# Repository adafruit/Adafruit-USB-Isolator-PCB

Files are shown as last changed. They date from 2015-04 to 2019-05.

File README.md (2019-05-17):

# Adafruit USB Isolator PCB
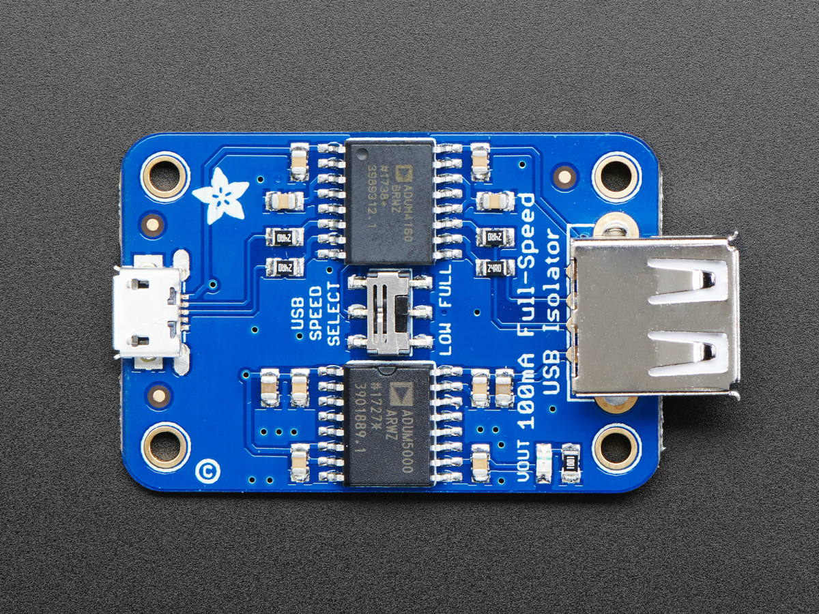
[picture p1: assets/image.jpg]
<a href="http://www.adafruit.com/products/2107"><br/>
Click here to purchase one from the Adafruit shop</a>

This handy little low-cost USB Isolator is exactly what you need to provide protection against harmful noise, ground loops, surges, and spikes. Works with any 1.5Mbps (low speed) or 12Mbps (full speed) USB device. Not for high speed USB devices, often used for video cameras (check your product to make sure its low/full compatible) Based on Analog Device's USB isolators

PCB files for the Adafruit USB Isolator. The format is EagleCAD schematic and board layout
- https://www.adafruit.com/product/2107

### License

Adafruit invests time and resources providing this open source design, please support Adafruit and open-source hardware by purchasing products from [Adafruit](https://www.adafruit.com)!

All text above must be included in any redistribution

Designed by Limor Fried/Ladyada for Adafruit Industries.
Creative Commons Attribution/Share-Alike, all text above must be included in any redistribution. 
See license.txt for additional information.

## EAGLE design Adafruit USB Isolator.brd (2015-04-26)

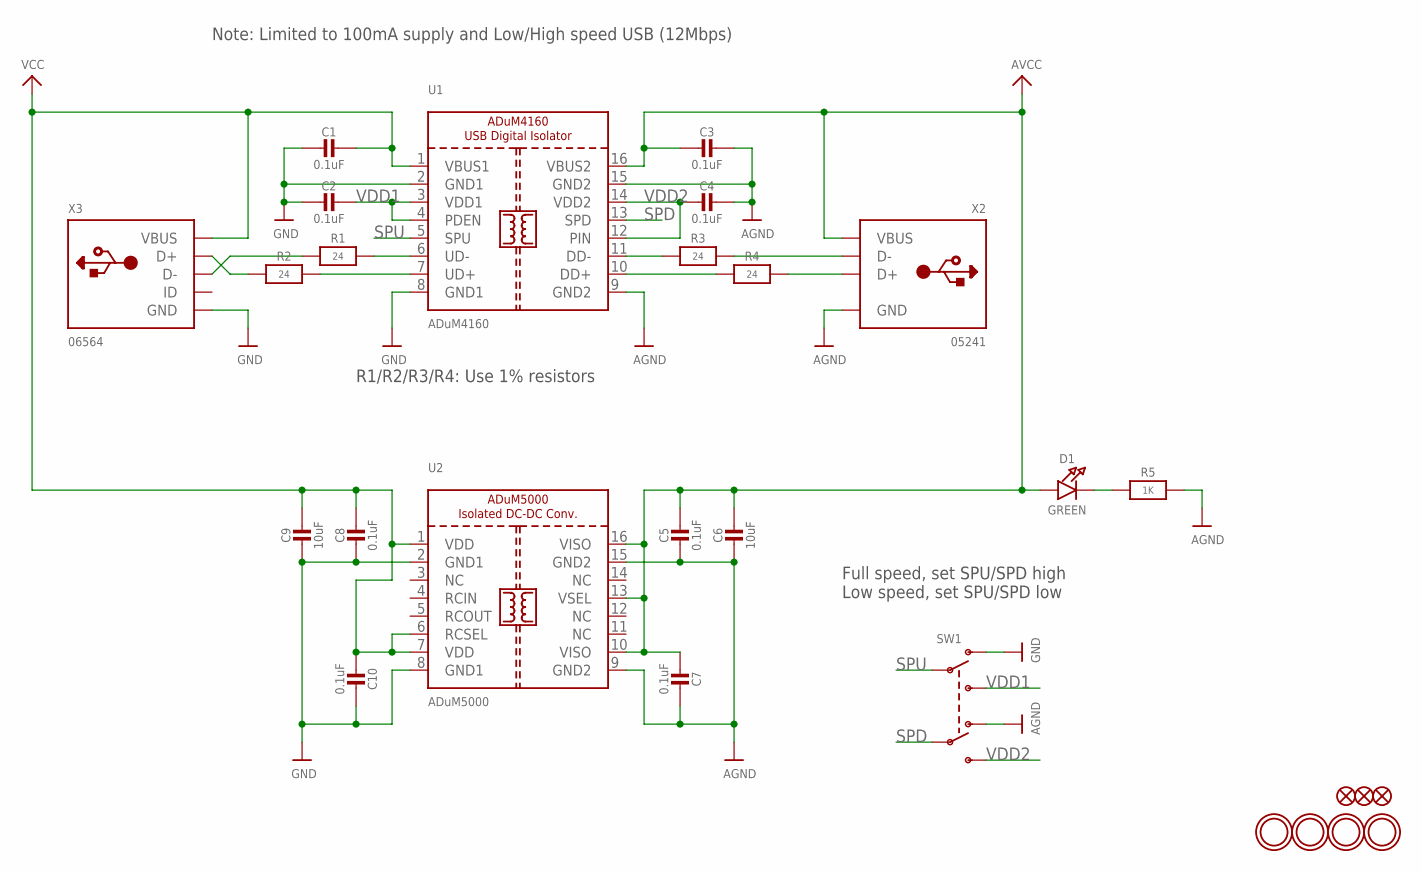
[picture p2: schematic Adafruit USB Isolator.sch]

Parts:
C1, C2, C3, C4, C5, C7, C8, C10: 0.1uF; 0805-NO
C6, C9: 10uF; 0805-NO
D1: GREEN; CHIPLED_0805_NOOUTLINE
FID1, FID2, FID3: FIDUCIAL""; FIDUCIAL_1MM
R1, R2, R3: 24; 0805-NO
R4: 24; _0805MP
R5: 1K; 0805-NO
SW1: SWITCH_DPDTEG1390; EG1390
U1: ADuM4160; SOIC16WIDE
U2: ADuM5000; SOIC16WIDE
U$7, U$8, U$9, U$10: MOUNTINGHOLE2.5_THICK; MOUNTINGHOLE_2.5_PLATED_THICK
X2: 05241; USB_HOST-PTH
X3: 06564; USB-MINIB_LARGER

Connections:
AGND: C3.1, C4.1, C5.2, C6.2, C7.1, R5.2, SW1.O2, U1.9 (GND2), U1.15 (GND2), U2.9 (GND2), U2.15 (GND2), X2.GND
AVCC: C3.2, C5.1, C6.1, C7.2, D1.A, U1.16 (VBUS2), U2.10 (VISO), U2.13 (VSEL), U2.16 (VISO), X2.VBUS
GND: C1.2, C2.2, C8.2, C9.2, C10.1, SW1.O1, U1.2 (GND1), U1.8 (GND1), U2.2 (GND1), U2.8 (GND1), X3.GND, X3.GND1 (GND), X3.GND2 (GND), X3.GND3 (GND), X3.GND4 (GND)
unnamed: R2.1, X3.D+
unnamed: R2.2, U1.7 (UD+)
unnamed: R1.2, U1.6 (UD-)
unnamed: R1.1, X3.D-
unnamed: R4.1, U1.10 (DD+)
unnamed: R4.2, X2.D+
unnamed: R3.2, X2.D-
unnamed: R3.1, U1.11 (DD-)
unnamed: D1.C, R5.1
SPD: SW1.P2, U1.13 (SPD)
SPU: SW1.P1, U1.5 (SPU)
VCC: C1.1, C8.1, C9.1, C10.2, U1.1 (VBUS1), U2.1 (VDD), U2.6 (RCSEL), U2.7 (VDD), X3.VBUS
VDD1: C2.1, SW1.S1, U1.3 (VDD1), U1.4 (PDEN)
VDD2: C4.2, SW1.S2, U1.12 (PIN), U1.14 (VDD2)

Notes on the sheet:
R1/R2/R3/R4: Use 1% resistors
Note: Limited to 100mA supply and Low/High speed USB (12Mbps)
Full speed, set SPU/SPD high Low speed, set SPU/SPD low

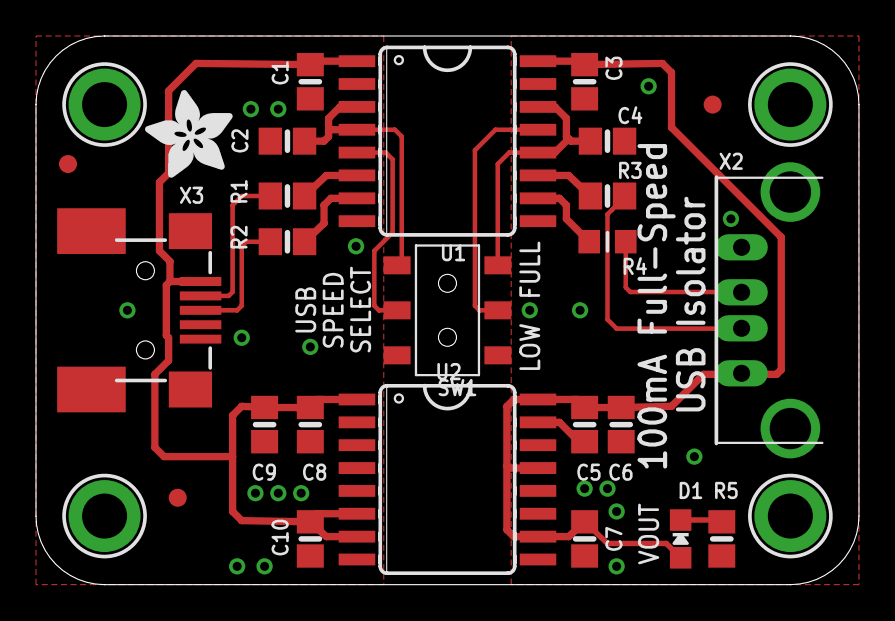
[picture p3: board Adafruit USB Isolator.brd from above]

Board: 2 copper layers, 45.7 x 30.5 mm, 30 parts (1 on the bottom side), 17 nets.

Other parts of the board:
U$14: ADAFRUIT_5MM
U$16: ADAFRUIT_TEXT_30MM

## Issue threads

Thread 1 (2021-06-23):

Stl file

adelira415, 2021-06-23:
Hi. Can you provide a CAD model for the isolator?

When trying to open the brd file in Solidworks/Inventor it gives an error that a .lib file is mising.

ladyada, 2021-06-23:
its in eaglecad

Closed 2021-06-23.

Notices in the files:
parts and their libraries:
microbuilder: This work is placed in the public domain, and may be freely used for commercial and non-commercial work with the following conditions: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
